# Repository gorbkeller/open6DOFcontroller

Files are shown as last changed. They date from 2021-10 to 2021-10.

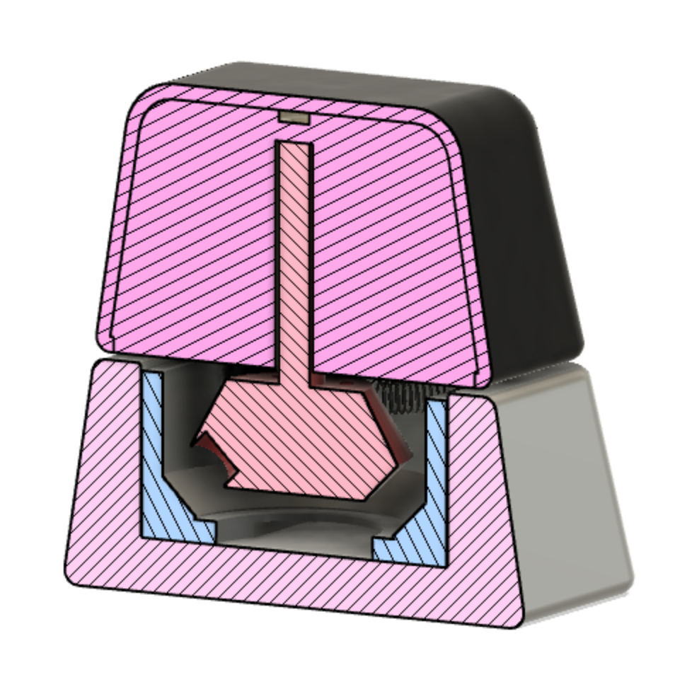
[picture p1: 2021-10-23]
imgs/o6DOFc_V0.1.png

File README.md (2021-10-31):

# open6DOFcontroller
## Gordon Keller
### 10/23/21

*** An open-source 6DOF (Degrees Of Freedom) controller. ***

This project leverages several different packages to enable 6DOF input akin to the closed-source/proprietary hardware 3D Connexion SpaceMouse.

In this original form, it combines:
* FIRMWARE: The QMK Firmware project (link) -- TBD
* ELECTRONICS: KiCAD (link)
* HARDWARE/MODELS: Autodesk Fusion360 (link), though intention to eventually port to FreeCAD.

This controller is based on hall-effect sensors. The first pass of algorithms developed to convert magnetic signals to 6DOF aren't very sophistocated and could use a major rework.
Theoretically, it can be used to control any 3D virtualized perspective/object. Eventually, I want to use it to fly the Lynchpin drone (link) in simulation and in IRL too ;)
I've included in this first installment a driver written for Fusion360 camera view control as an example useage. This is written using the Fusion360 Scripting API.

The outputs of the one-handed module are given in either XYZ-translation + WIJK-Quaternion ("pose-mode") or XYZ-translation + Roll/Pitch/Yaw ("euler-mode"). 

Some people might not like the 6DOF with one hand control, so a fork of this repo (3DOF-3DOF) should be created eventually which splits the device in two for use with both hands. This method involves less signal processing but requires multiple PCBs.

In-depth plan TBD! - gribgrob_k

[The main bodies of the V0.1 design](imgs/o6DOFc_V0.1.png)

TO-DO:
High-priority:
1. Validate first version of the flex PCB
2. Finish start-up calibration sequence
3. Port data processing to fusion script for proof-of-concept

Low-priority:
1. Port output values from example Fusion script to the dedicated MCU (arduino initially)
2. Develop QMK-side of the device

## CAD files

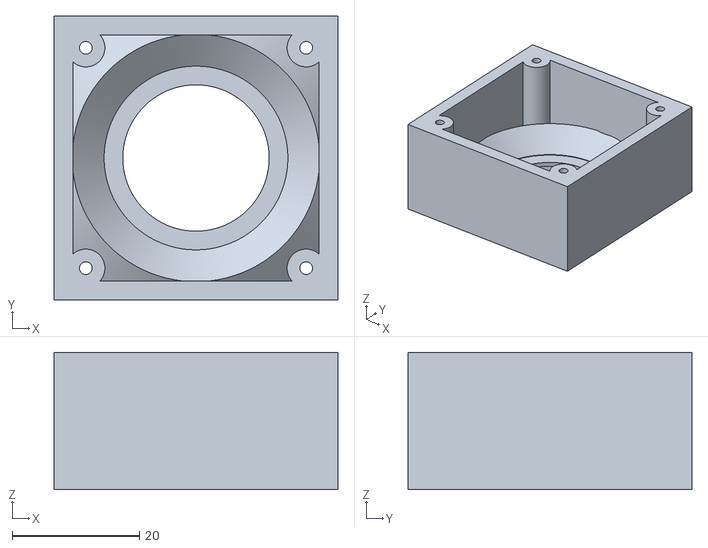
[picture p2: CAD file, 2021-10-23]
CAD/V0.1/o6DOFc_chassy.stl
44.6 x 44.6 x 21.5

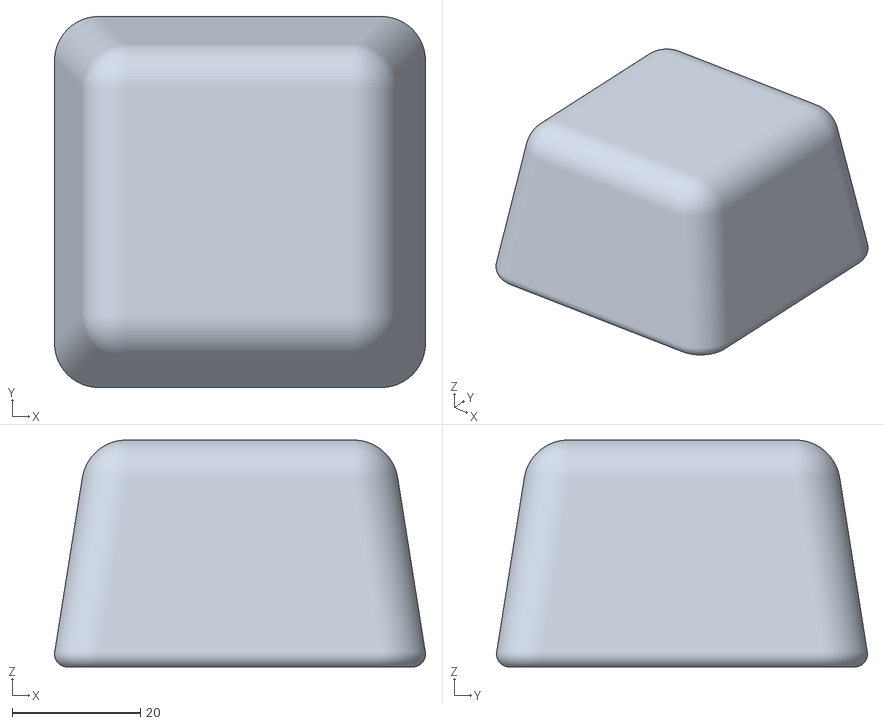
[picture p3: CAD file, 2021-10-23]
CAD/V0.1/o6DOFc_knob_skin.stl
58.0 x 58.0 x 35.5

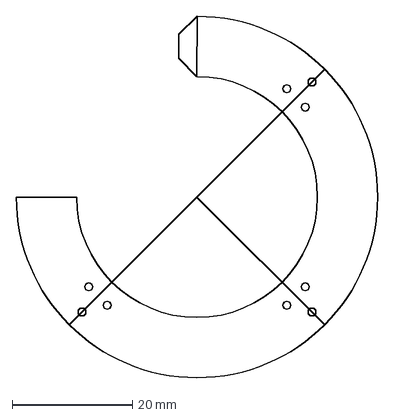
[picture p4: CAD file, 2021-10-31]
PCB/V1.0/o6DOFc_flex_pcb/hes_layout.dxf
60.0 x 60.0 mm

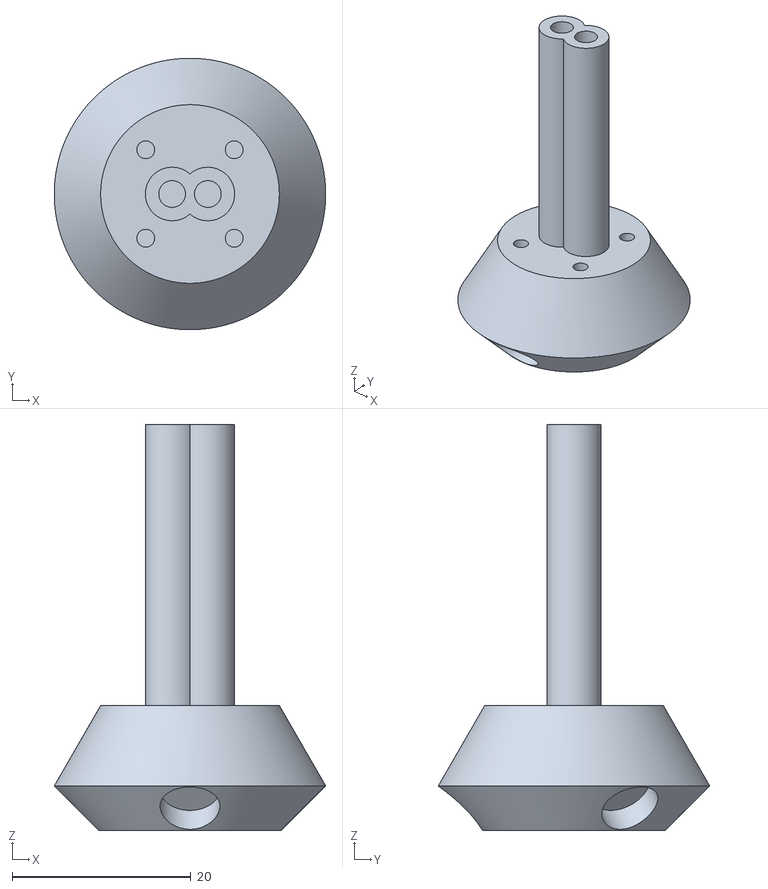
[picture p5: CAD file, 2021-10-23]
CAD/V0.1/o6DOFc_suspension_piece.stl
30.4 x 30.4 x 45.5

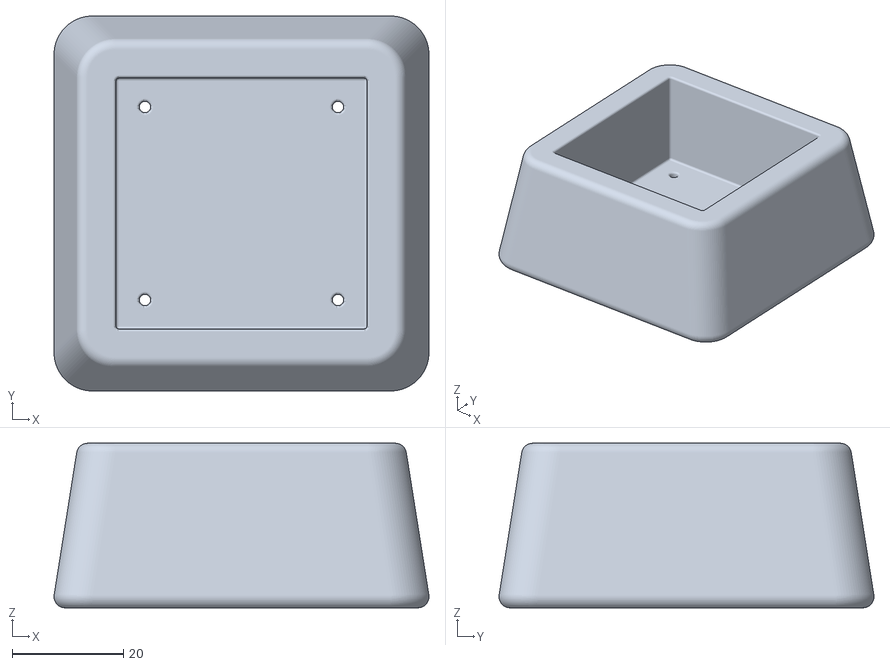
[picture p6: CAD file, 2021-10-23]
CAD/V0.1/o6DOFc_base.stl
67.3 x 67.3 x 29.5

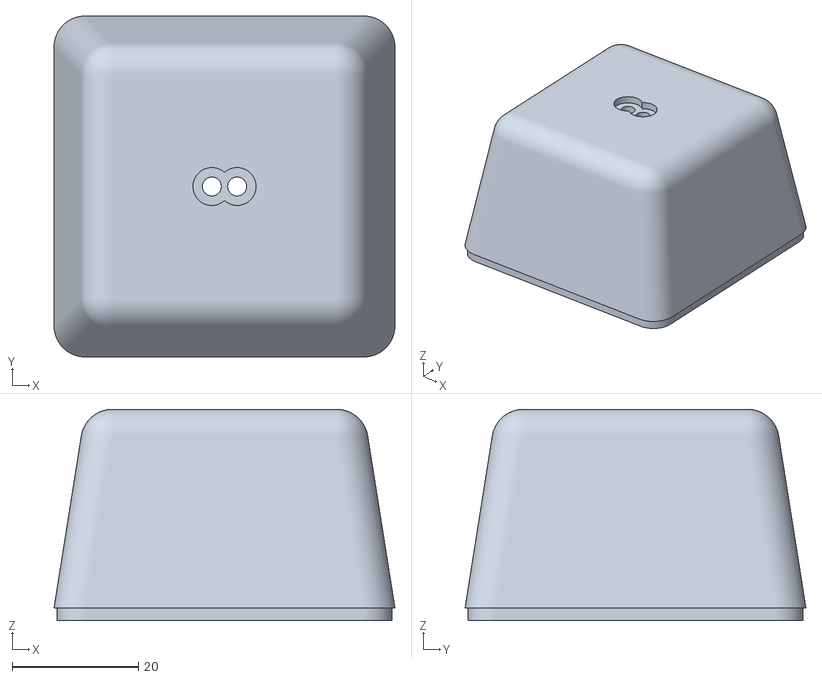
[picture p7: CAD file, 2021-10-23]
CAD/V0.1/o6DOFc_knob.stl
54.0 x 54.0 x 33.5

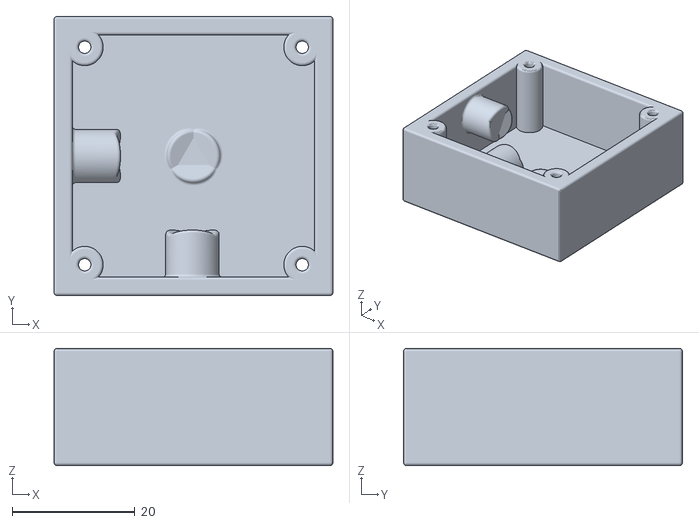
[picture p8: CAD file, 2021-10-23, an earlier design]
CAD/V0.0/six_dof_chassy.stl
45.4 x 45.4 x 19.1

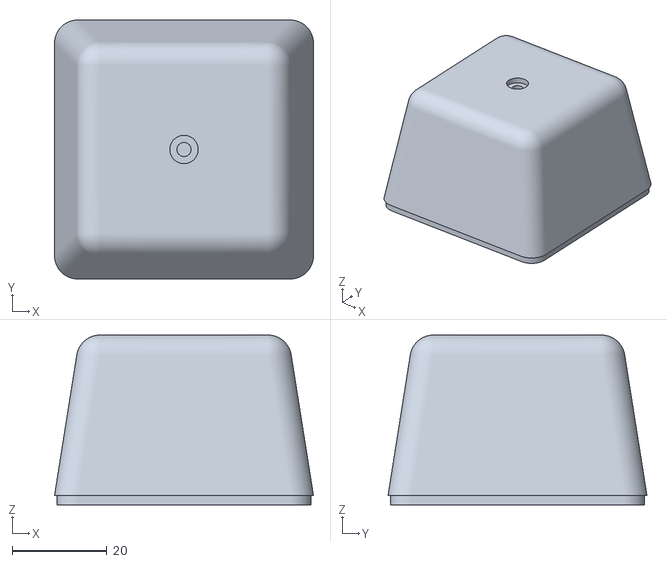
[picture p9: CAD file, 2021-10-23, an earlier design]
CAD/V0.0/six_dof_knob.stl
54.7 x 54.7 x 35.9

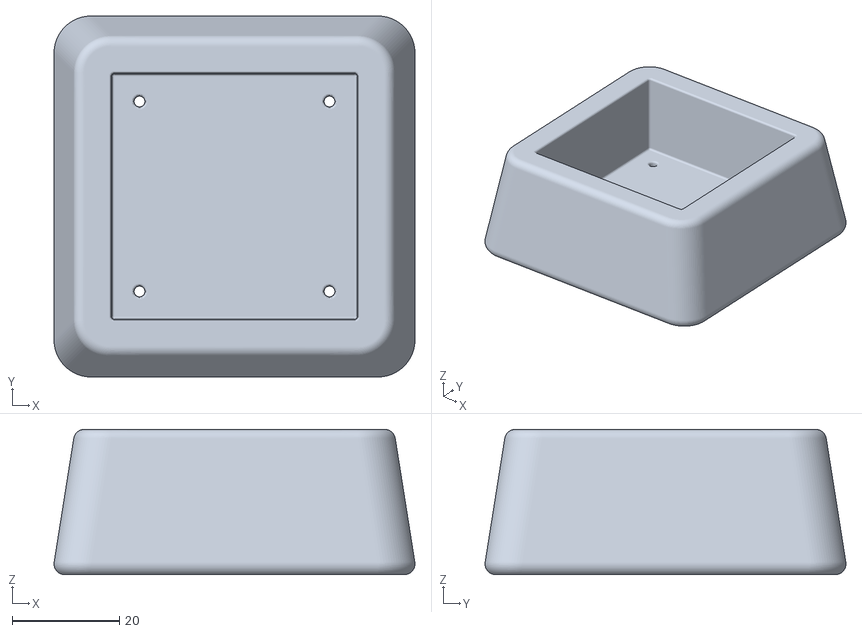
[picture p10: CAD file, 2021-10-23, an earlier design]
CAD/V0.0/six_dof_baxe.stl
67.3 x 67.3 x 27.1

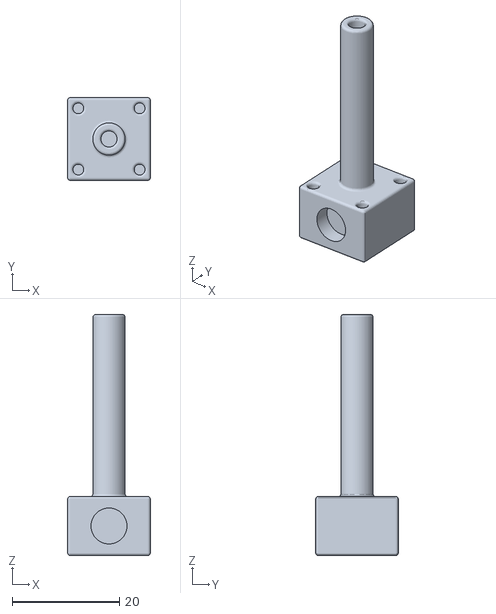
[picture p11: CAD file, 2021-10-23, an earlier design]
CAD/V0.0/six_dof_suspension_piece.stl
15.4 x 15.4 x 44.9

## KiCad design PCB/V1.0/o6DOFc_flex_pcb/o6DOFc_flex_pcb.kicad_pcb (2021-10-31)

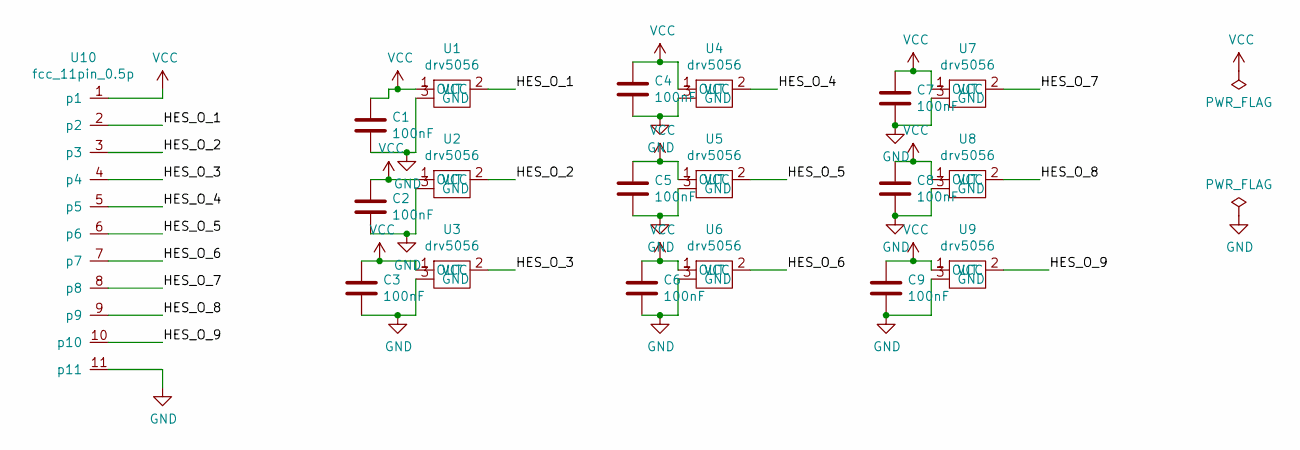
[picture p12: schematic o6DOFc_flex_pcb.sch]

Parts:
C1, C2, C3, C4, C5, C6, C7, C8, C9: 100nF; C_0603_1608Metric
U1, U2, U3, U4, U5, U6, U7, U8, U9: drv5056; SOT-23
U10: fcc_11pin_0.5p; ffc_11_pin_0.5_p

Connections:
/HES_O_1: U1.2 (OUT), U10.2 (p2)
/HES_O_2: U2.2 (OUT), U10.3 (p3)
/HES_O_3: U3.2 (OUT), U10.4 (p4)
/HES_O_4: U4.2 (OUT), U10.5 (p5)
/HES_O_5: U5.2 (OUT), U10.6 (p6)
/HES_O_6: U6.2 (OUT), U10.7 (p7)
/HES_O_7: U7.2 (OUT), U10.8 (p8)
/HES_O_8: U8.2 (OUT), U10.9 (p9)
/HES_O_9: U9.2 (OUT), U10.10 (p10)
GND: C1.2, C2.2, C3.2, C4.2, C5.2, C6.2, C7.2, C8.2, C9.2, U1.3 (GND), U2.3 (GND), U3.3 (GND), U4.3 (GND), U5.3 (GND), U6.3 (GND), U7.3 (GND), U8.3 (GND), U9.3 (GND), U10.11 (p11)
VCC: C1.1, C2.1, C3.1, C4.1, C5.1, C6.1, C7.1, C8.1, C9.1, U1.1 (VCC), U2.1 (VCC), U3.1 (VCC), U4.1 (VCC), U5.1 (VCC), U6.1 (VCC), U7.1 (VCC), U8.1 (VCC), U9.1 (VCC), U10.1 (p1)

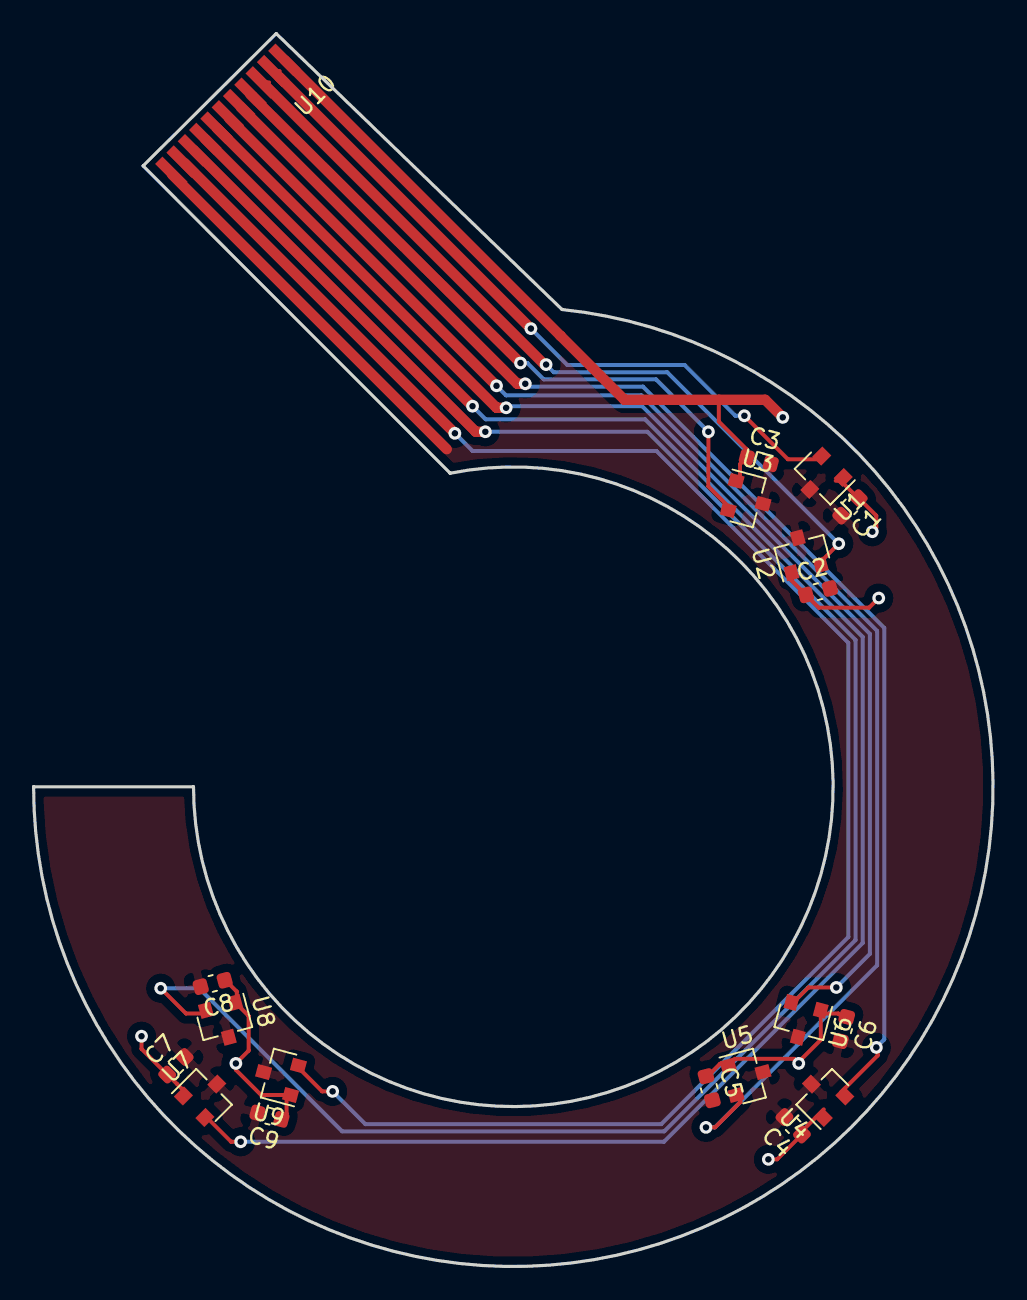
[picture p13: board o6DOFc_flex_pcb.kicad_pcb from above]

Board: 2 copper layers, 60.0 x 77.1 mm, 19 parts (0 on the bottom side), 11 nets.

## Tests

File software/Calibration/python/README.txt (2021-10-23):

README
Gordon Keller
9/12/21

This directory contains programs for testing, calibrating, and using the hall-effect based 6-dof mouse. 

## Files
6DOFMouseCalibration.py: not currently working -- switched over to the v2.
6DOFMouseCalibration_v2.py:

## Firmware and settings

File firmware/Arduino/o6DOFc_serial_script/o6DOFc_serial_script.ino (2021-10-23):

const int pinX1 = A3;
const int pinX2 = A2;
const int pinX3 = A1;

const int pinY1 = A9;
const int pinY2 = A8;
const int pinY3 = A7;

const int pinZ1 = A6;
const int pinZ2 = A10;
const int pinZ3 = A0;

void setup() {
  pinMode(pinX1, INPUT);
  pinMode(pinX2, INPUT);
  pinMode(pinX3, INPUT);
  pinMode(pinY1, INPUT);
  pinMode(pinY2, INPUT);
  pinMode(pinY3, INPUT);
  pinMode(pinZ1, INPUT);
  pinMode(pinZ2, INPUT);
  pinMode(pinZ3, INPUT);
  Serial.begin(9600);
}
 
void loop() {
  int X1 = analogRead(pinX1);
  int X2 = analogRead(pinX2);
  int X3 = analogRead(pinX3);
  int Y1 = analogRead(pinY1);
  int Y2 = analogRead(pinY2);
  int Y3 = analogRead(pinY3);
  int Z1 = analogRead(pinZ1);
  int Z2 = analogRead(pinZ2);
  int Z3 = analogRead(pinZ3);
  Serial.print(X1);
  Serial.print("_");
  Serial.print(X2);
  Serial.print("_");
  Serial.print(X3);
  Serial.print("_");
  Serial.print(Y1);
  Serial.print("_");
  Serial.print(Y2);
  Serial.print("_");
  Serial.print(Y3);
  Serial.print("_");
  Serial.print(Z1);
  Serial.print("_");
  Serial.print(Z2);
  Serial.print("_");
  Serial.println(Z3);
  delay(10);
}

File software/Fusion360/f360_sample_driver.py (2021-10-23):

#Author-
#Description-

import adsk.core, adsk.fusion, adsk.cam, traceback,math
import threading, random, json
import os,sys
sys.path.append('/Library/Frameworks/Python.framework/Versions/3.8/lib/python3.8/site-packages')
import serial

# global vars
app = None
ui = adsk.core.UserInterface.cast(None)
handlers = []
stopFlag = None
myCustomEvent = 'MyCustomEventId'
customEvent = None

# axis assignment: use 'x','y','z' to assign
zoom = 'y'
in_plane_rot = None
pan_lr = 'x'
pan_ud = 'w'
rot_lr = 'z'
rot_ud = None

# initialize biases to ideal values before initialization
bias_terms = {'x': 0,'y': 0,'z': 0,'w':0}

# remap val from range r1 to range r2
scale = lambda v,r1,r2 : ((v - r1[0]) / (r1[1]-r1[0])) * (r2[1]-r2[0]) + r2[0]

# thresholding for joystick zero approximation
active = lambda v : v < 430.0 or v > 580.0

def rotate(a,angle,axis,orig):
    # helper function that rotates 'a' (Point3D or Vector3D) 'angle' in radians
    # around 'axis' (Vector3D) at 'orig' (Point3D)
    mat = adsk.core.Matrix3D.create()
    mat.setToRotation(angle,axis,orig)
    a.transformBy(mat)

def translate(a,dist,axis):
    # helper function that moves 'a' along 'axis' an amount 'dist'
    axis.normalize()
    axis.scaleBy(dist)
    a.translateBy(axis)

def move_camera(app,view,axes):
    # x=up/down,y=left/right,z=twist right/left
    ui = app.userInterface
    try:
        camera = view.camera
        
        #get camera parameters
        target = camera.target
        up = camera.upVector
        prev = camera.eye
        extents = camera.viewExtents

        # fix biases
        axes = apply_bias_terms(axes)

        # in-plane rotate around centerline
        if (in_plane_rot != None):
            val = axes[in_plane_rot]
            if active(val):
                rotate(up,math.pi/180.0*scale(val,[0.0,1024.0],[-10.0,10.0]), \
                    prev.vectorTo(target), \
                    adsk.core.Point3D.create(0,0,0))

        # zoom in/out
        if (zoom != None):
            val = axes[zoom]
            if active(val):
                zoom_scale = extents*scale(val,[0.0,1024.0],[0.25,1.75])
                if zoom_scale > 0.000001:
                    extents = zoom_scale

        # pan up/down
        if (pan_ud != None):
            val = axes[pan_ud]
            if active(val):
                translate(prev,scale(val,[0.0,1024.0],[-1.0,1.0]),up.copy())
                translate(target,scale(val,[0.0,1024.0],[-1.0,1.0]),up.copy())

        # pan left/right
        if (pan_lr != None):
            val = axes[pan_lr]
            if active(val):
                sideways = up.copy()
                rotate(sideways,math.pi/2, \
                    prev.vectorTo(target), \
                    adsk.core.Point3D.create(0,0,0))
                translate(prev,scale(val,[0.0,1024.0],[-1.0,1.0]),sideways.copy())
                translate(target,scale(val,[0.0,1024.0],[-1.0,1.0]),sideways.copy())
        
        # horiz rotate around target
        if (rot_lr != None):
            val = axes[rot_lr]
            if active(val):
                rotate(prev,math.pi/180.0*scale(val,[0.0,1024.0],[-10.0,10.0]), \
                    up, \
                    target)

        # vertical rotate around target
        if (rot_ud != None):
            val = axes[rot_ud]
            if active(val):
                # make axis orthogonal to up vec about the target to use as axis
                sideways = up.copy()
                rotate(sideways,math.pi/2,prev.vectorTo(target),target)
                rotate(prev,math.pi/180.0*scale(val,[0.0,1024.0],[-10.0,10.0]), \
                    sideways, \
                    target)
                rotate(up,math.pi/180.0*scale(val,[0.0,1024.0],[-10.0,10.0]), \
                    sideways, \
                    adsk.core.Point3D.create(0,0,0))

        camera.eye = prev
        camera.target = target
        camera.upVector = up
        camera.viewExtents = extents

        camera.isSmoothTransition = False
        view.camera = camera
        adsk.doEvents()
        view.refresh()

    except:
        ui = app.userInterface
        if ui:
            ui.messageBox('Failed:\n{}'.format(traceback.format_exc()))

# helper function to calculate adjusted inputs by bias
def apply_bias_terms(input_terms):
    for key, value in input_terms.items():
        f = 0.0
        if value >= bias_terms[key]:
            f = (value-1023.0)*(-1.0/(1023.0-bias_terms[key]))
        else:
            f = (value)*(1.0/(bias_terms[key]))
        input_terms[key] = value+f*(1023.0/2.0 - bias_terms[key])
    return input_terms


# The event handler that responds to the custom event being fired.
class ThreadEventHandler(adsk.core.CustomEventHandler):
    def __init__(self):
        super().__init__()
    def notify(self, args):
        try:
            # Get the value from the JSON data passed through the event.
            eventArgs = json.loads(args.additionalInfo)
            
            # move camera based on vals 0-1023 on each axis
            move_camera(app, app.activeViewport,eventArgs)
            
        except:
            if ui:
                ui.messageBox('Failed:\n{}'.format(traceback.format_exc()))


# The class for the new thread.
class MyThread(threading.Thread):
    def __init__(self, event):
        threading.Thread.__init__(self)
        self.stopped = event

    def run(self):
        # Every five seconds fire a custom event, passing a random number.
        while not self.stopped.wait(0.02):
            with serial.Serial('/dev/cu.usbmodem141101', 9600, timeout=100) as ser:
                line = ser.readline()   # read a '\n' terminated line
                try: 
                    line = line.decode("utf-8").split('_')
                    args = {'x': int(line[0]),'y': int(line[1]),'z': int(line[2]),'w': int(line[3])}
                    app.fireCustomEvent(myCustomEvent, json.dumps(args)) 
                except:
                    pass

# subprocess to gauge biases of joystick using average of 10 samples
def initialize_joystick():
    bt = {'x': 0,'y': 0,'z': 0,'w':0}
    with serial.Serial('/dev/cu.usbmodem141101', 9600, timeout=100) as ser:
        for i in range(0,10):
            line = ser.readline()   # read a '\n' terminated line
            try: 
                line = line.decode("utf-8").split('_')
                bt['x'] += int(line[0])
                bt['y'] += int(line[1])
                bt['z'] += int(line[2])
                bt['w'] += int (line[3])
            except:
                pass
    bt = {k: v / 10.0 for k, v in bt.items()}
    return bt
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

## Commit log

2021-10-23 Added Fusion360 example driver
2021-10-23 Added the V0.0 stls
    [six_dof_baxe.stl, six_dof_chassy.stl, six_dof_knob.stl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]
2021-10-23 Added v0.1 STLs
    [o6DOFc_base.stl, o6DOFc_chassy.stl, o6DOFc_knob.stl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]
2021-10-23 Uploading initial KiCAD project
    [6dof_hall.kicad_pcb, 6dof_hall.sch]
2021-10-23 Moved calibration and testing files to a new direcotry
2021-10-23 added the Fusion360 sample driver for adjusting camera positionw
2021-10-31 added first variant of the 9-sensor flex PCB
    [hes_layout.dxf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]
2021-10-31 Updated to-dos to reflect first edition of the flex pcb done
